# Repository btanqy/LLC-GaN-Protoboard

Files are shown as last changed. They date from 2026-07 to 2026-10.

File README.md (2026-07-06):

# LLC-GaN-Protoboard

This board will be a prototype GaN based LLC converter, with a target rating of 80W with 24V input to 400V output, ideally for renewable power conversion and high voltage applications in plasma generation. 

This board will be controlled by and mounted on top of the [LAUNCHXL-F28P55X](https://www.digikey.com/en/products/detail/texas-instruments/LAUNCHXL-F28P55X/22674628). It will be based on the reference design for TIDA-010062, minus the PFC element.

The board is made in KiCad while the code is done in Code Composer Studio by TI. 

Some resources that were used for reference during board design:
- [Pinout Map](https://www.ti.com/lit/ml/spaz056/spaz056.pdf?ts=1783172662507)
- [LaunchPad Hardware Design Guidelines](https://www.ti.com/lit/an/slaa542/slaa542.pdf)
- [F28P55X Datasheet](https://www.ti.com/lit/ds/sprsp85d/sprsp85d.pdf?ts=1783173915619)
- [Open Magnetics](https://openmagnetics.com)

- [LLC Topology](https://e2e.ti.com/cfs-file/__key/communityserver-discussions-components-files/196/Ch4.pdf)
- [LLC Switches and Tank](https://www.monolithicpower.com/learning/resources/understanding-llc-operation-part-i-power-switches-and-resonant-tank)
- [Example LLC Design](https://www.infineon.com/assets/row/public/documents/24/42/infineon-design-example-resonant-llc-converter-operation-and-design-applicationnotes-en.pdf)

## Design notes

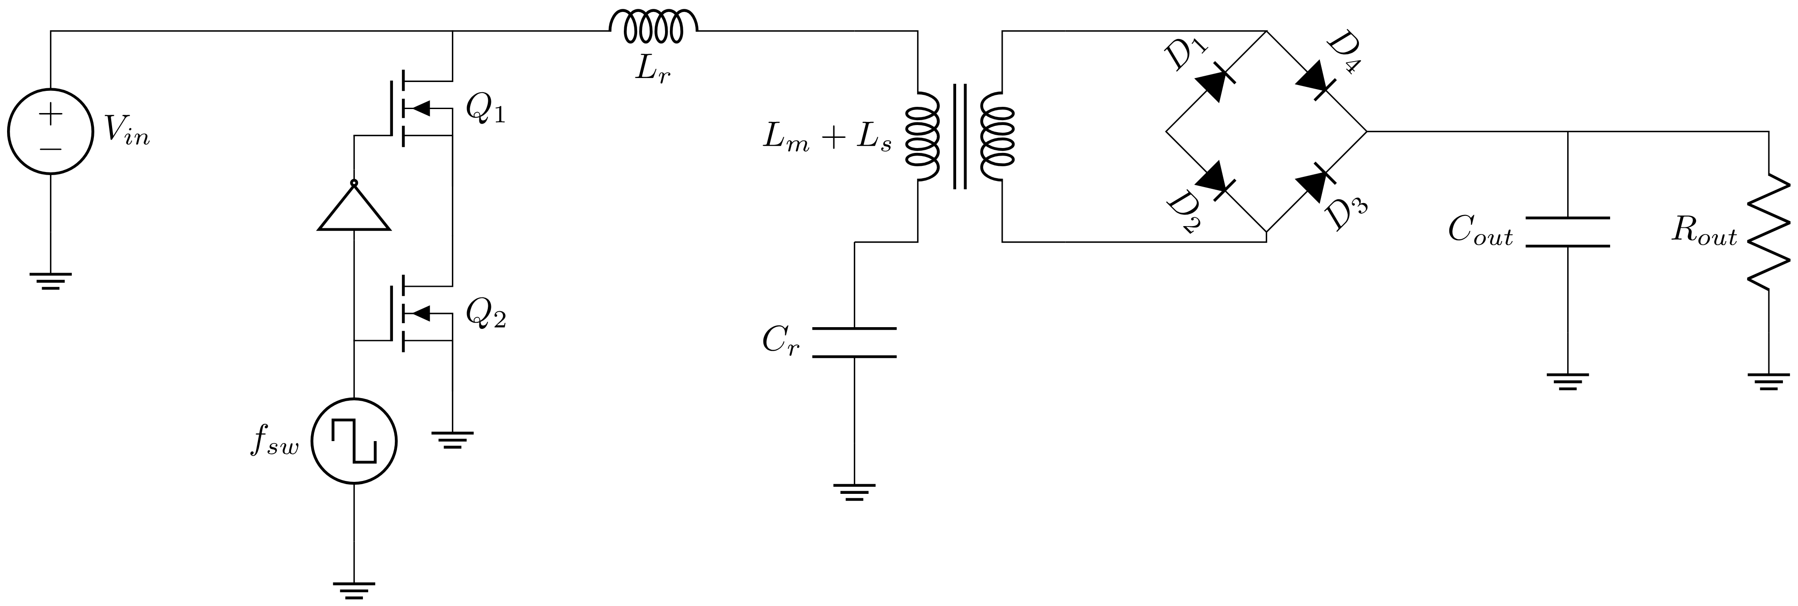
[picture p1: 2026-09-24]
circuitikz schematics/llc.png

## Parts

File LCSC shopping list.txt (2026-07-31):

2* 67996-420HLF (2x20 pin header)
2* FAN73912AMX (1200V half-bridge gate driver)
2* GAN7R0-150LBE (GAN)
2* 9561250802 (Ferrite core)
1* KAPTON-TAPE40MM (40mm polyimide insulation tape)
1* RT2010FKE075RL (75mΩ current sense resistor)
25* 5019 (PCB test points)
4* ADS12B3-ASARH (SiC schottky)
1* C1812C104KDRACTU (100nF ceramic capacitor, 1812 for rectifier)
1* C1206C302JCGACTU (3nF ceramic capacitor, 1206 for tank)
1* WSC25155R000FEA (5Ω current sense)
1* RT2010FKE075RL (50mΩ current sense)
10* C0603C104K5RACTU (0.1uF 0603 ceramic capacitor)
10* CL21B104KBCNNNC (1uf 0603 ceramic capacitor)
1* BU-P6883 (binding post)

2/20 turn transformer
ferrite core needs a 60um gap (1.08uh magnetizing inductance)
10 turns, 6.25 starting radius, 0.254 width, 0.4 spacing

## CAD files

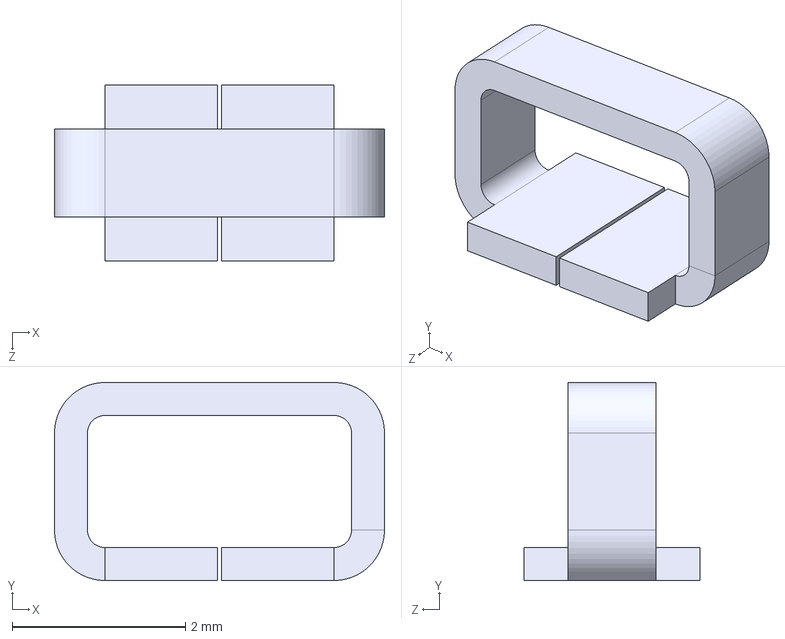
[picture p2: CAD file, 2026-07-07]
Parts/5019/3D/5019.stp
3.81 x 2.29 x 2.03 mm

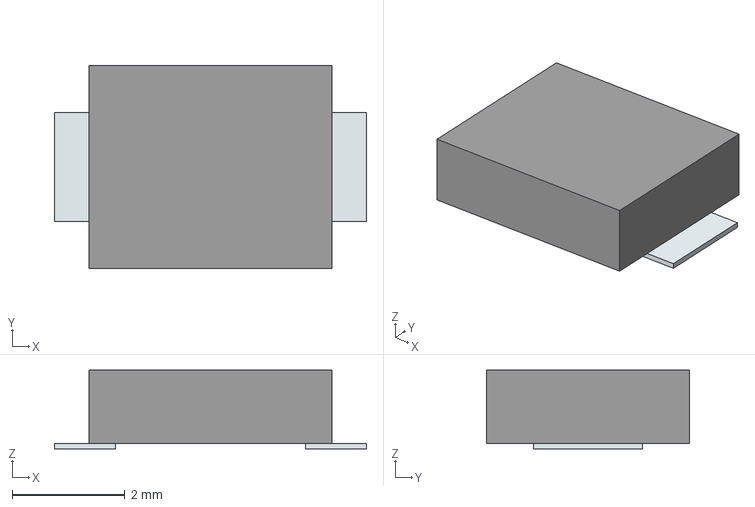
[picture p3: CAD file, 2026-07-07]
Parts/ADS12B3-ASARH/3D/ADS12B3-ASARH.stp
5.53 x 3.60 x 1.40 mm
Pins

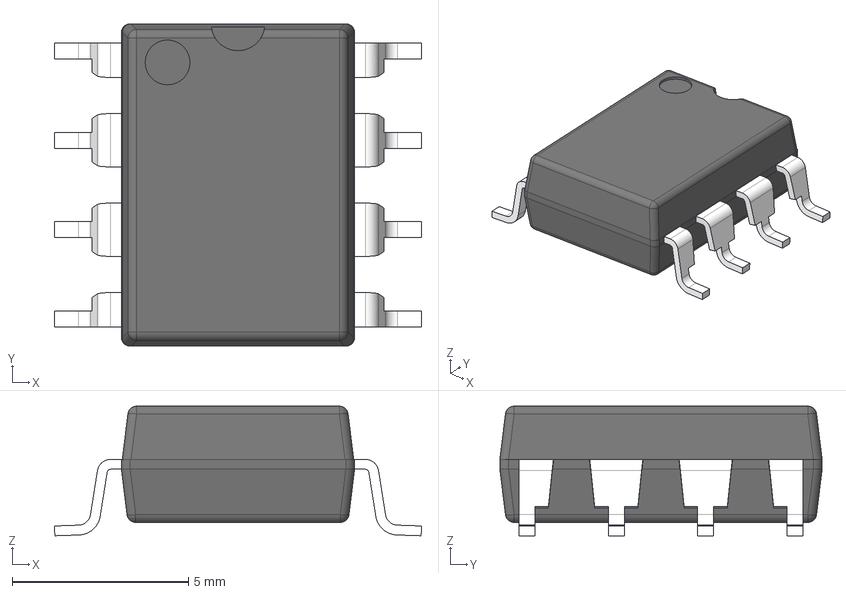
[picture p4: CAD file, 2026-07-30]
Parts/AMC1200SDUBR/AMC1200SDUBR/3D/AMC1200SDUBR.stp
10.4 x 9.15 x 3.68 mm
BODY-SO_AF0
LEAD-SO_AF1
LEAD-SO x 4
LEAD-SO_AF0
LEAD-SO_AF3
LEAD-SO_AF2

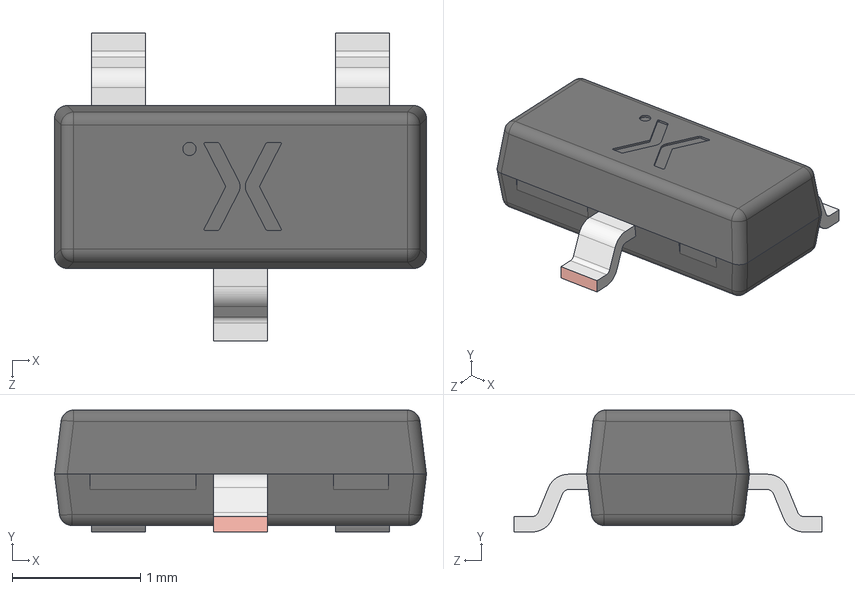
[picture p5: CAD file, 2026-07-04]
Parts/BZX84-C5V6,215/3D/BZX84-C5V6,215.stp
2.90 x 0.95 x 2.40 mm
SOT23 lower body
SOT23 Lead x 3
SOT23 Upper body

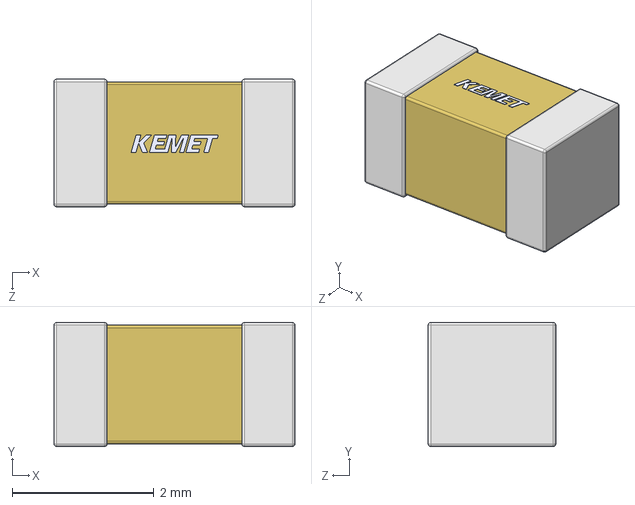
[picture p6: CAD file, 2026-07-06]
Parts/C1206C302JCGACTU/3D/C1206C302JCGACTU.stp
3.40 x 1.75 x 1.80 mm

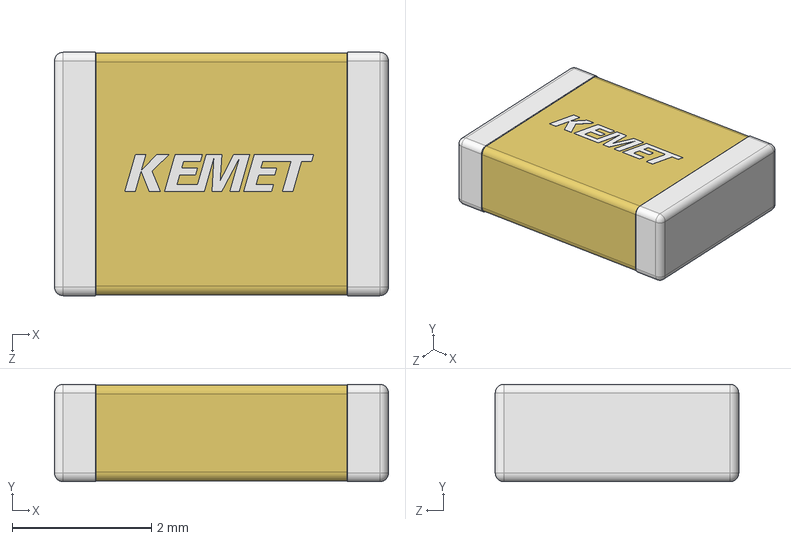
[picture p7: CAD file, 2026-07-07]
Parts/C1812C104KDRACTU/3D/C1812C104KDRACTU.stp
4.80 x 1.40 x 3.50 mm
Base_139
Termination_139 x 2

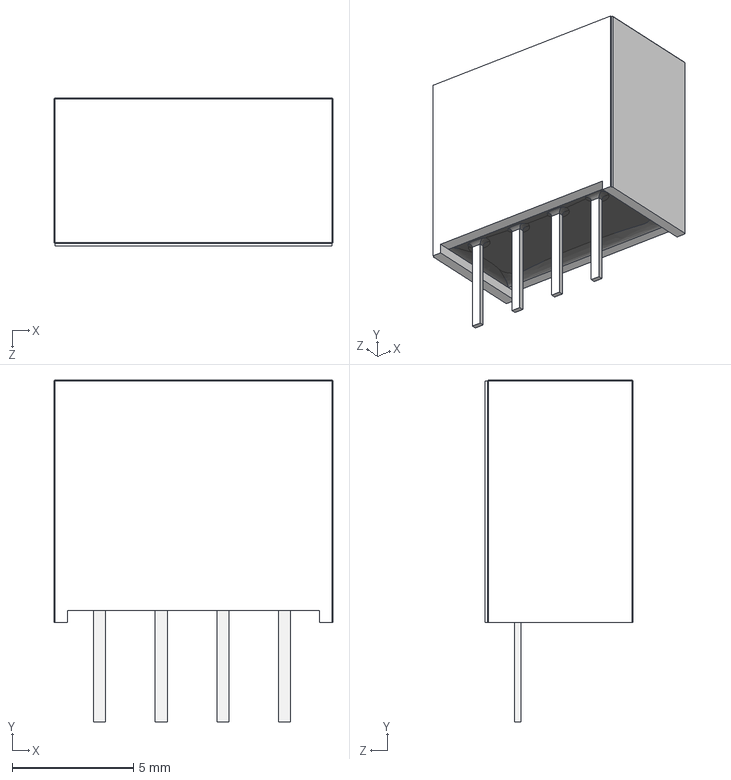
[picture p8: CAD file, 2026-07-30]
Parts/CME0303S3C/CME0303S3C/3D/CME0303S3C.stp
11.5 x 14.1 x 6.10 mm

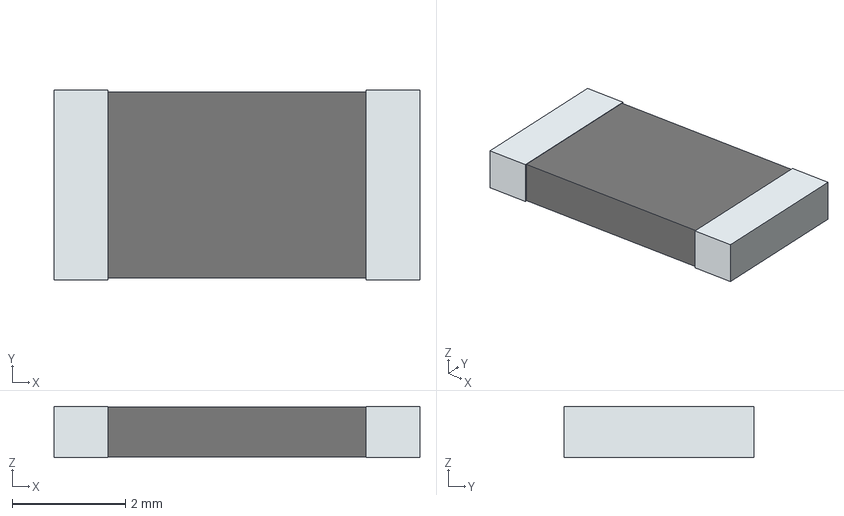
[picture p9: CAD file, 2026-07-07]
Parts/CRA2512-FZ-R050ELF/3D/CRA2512-FZ-R050ELF.stp
6.45 x 3.35 x 0.9 mm
term1
term2

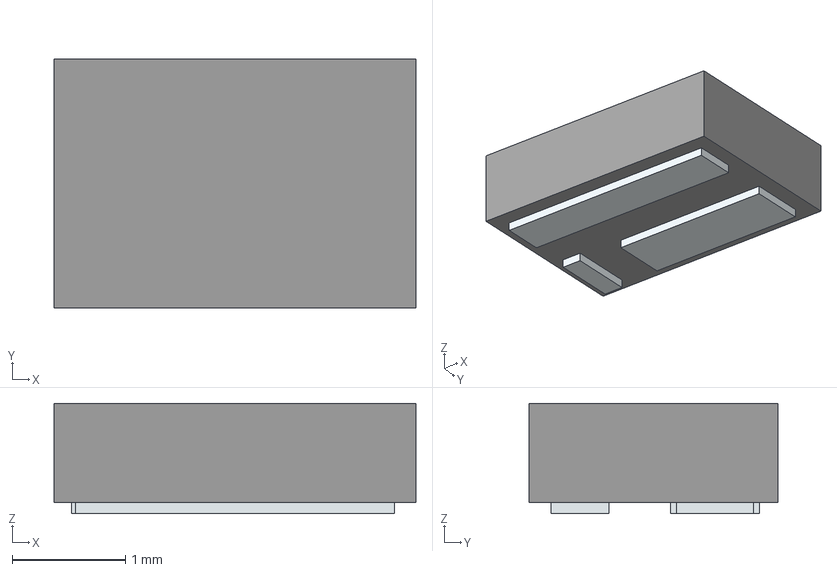
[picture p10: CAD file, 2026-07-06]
Parts/GAN7R0-150LBE/3D/GAN7R0-150LBE.stp
3.20 x 2.20 x 0.974 mm
Pins

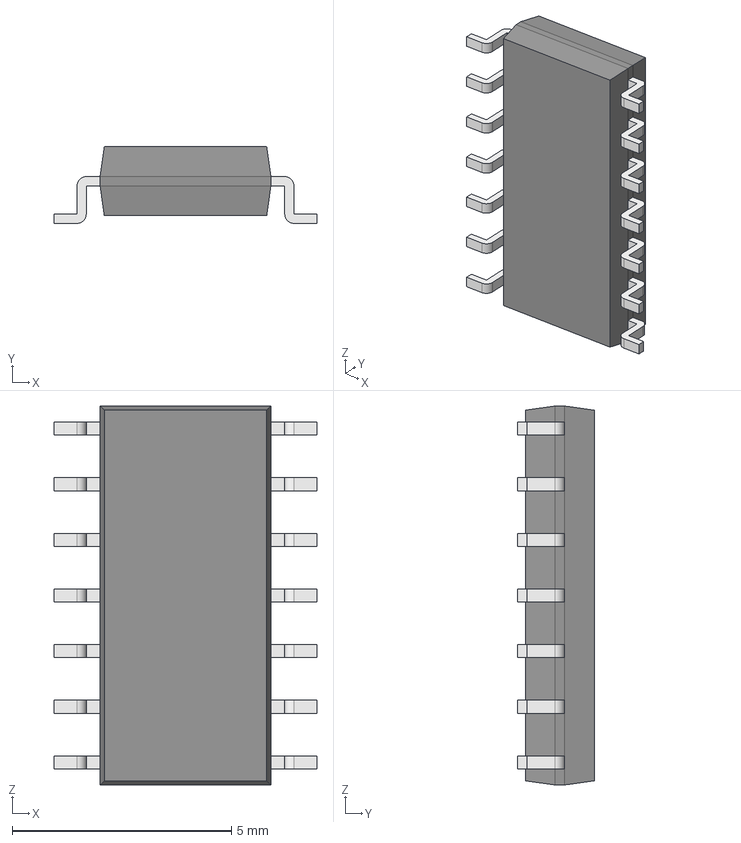
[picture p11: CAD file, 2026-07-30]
Parts/LM124DR/LM124DR.step
6.00 x 1.75 x 8.65 mm
Body001 (Mirror #1) x 7
XY-plane x 12
X-axis x 12

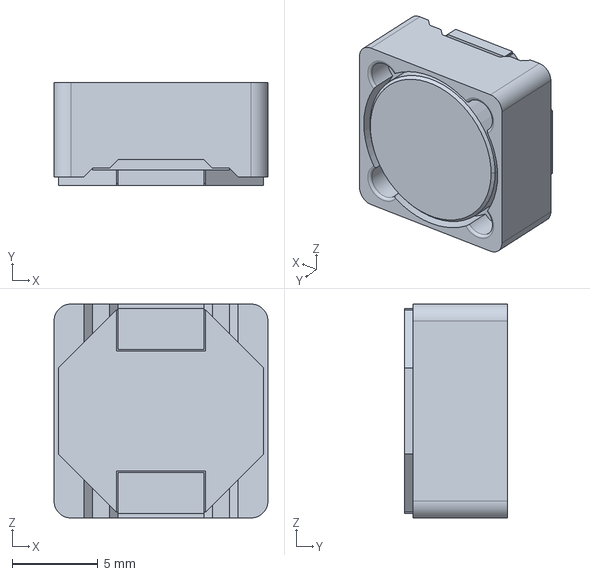
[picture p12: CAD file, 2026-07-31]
Parts/SRR1260-150M/SRR1260-150M/3D/SRR1260-150M.stp
12.5 x 6.00 x 12.5 mm

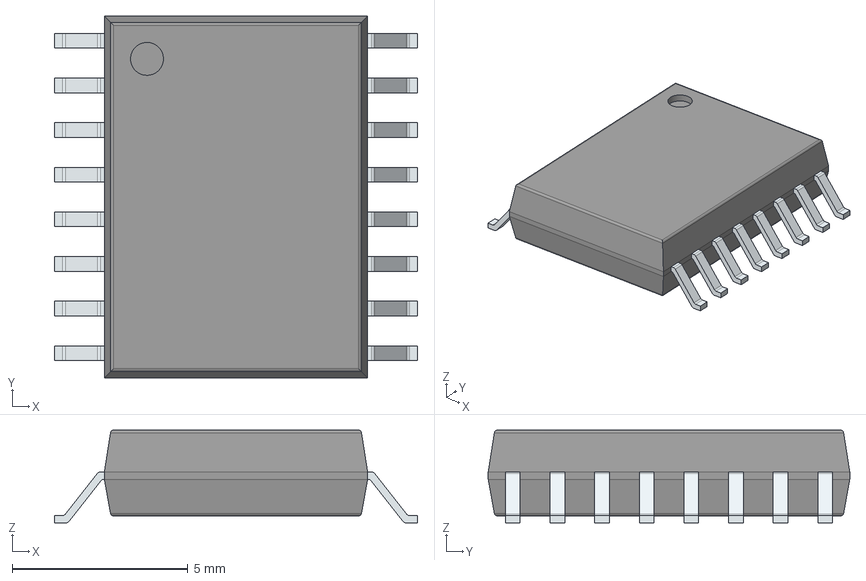
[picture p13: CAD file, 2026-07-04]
Parts/FAN73912AMX/3D/FAN73912AMX.stp
10.3 x 10.3 x 2.64 mm
PinsArrayLR

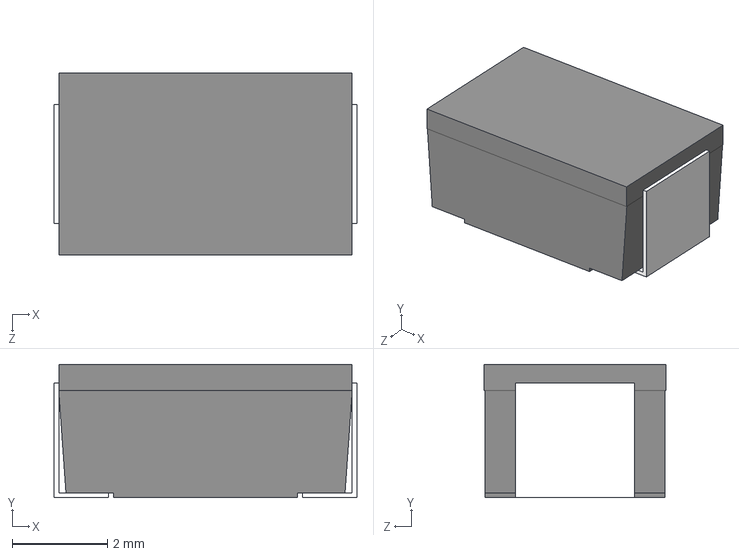
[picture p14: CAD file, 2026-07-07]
Parts/WSC25155R000FEA/3D/WSC25155R000FEA.stp
6.35 x 2.79 x 3.81 mm

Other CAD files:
Parts/5019/Allegro/5019.psm
Parts/5019/DEHDL/5019/chips/chips.prt
Parts/ADS12B3-ASARH/Allegro/ads12b3asarh.psm
Parts/ADS12B3-ASARH/DEHDL/ads12b3_asarh/chips/chips.prt
Parts/AMC1200SDUBR/AMC1200SDUBR/Allegro/sop254p1040x485-8n.psm
Parts/AMC1200SDUBR/AMC1200SDUBR/DEHDL/amc1200sdubr/chips/chips.prt
Parts/BZX84-C5V6,215/Allegro/sot95p230x110-3n.psm
Parts/BZX84-C5V6,215/DEHDL/bzx84_c5v6_215/chips/chips.prt
Parts/C1206C302JCGACTU/DEHDL/c1206c302jcgactu/chips/chips.prt
Parts/C1812C104KDRACTU/Allegro/c1812.psm
Parts/C1812C104KDRACTU/DEHDL/c1812c104kdractu/chips/chips.prt
Parts/CME0303S3C/CME0303S3C/Allegro/cme0303s3c.psm
Parts/CME0303S3C/CME0303S3C/DEHDL/cme0303s3c/chips/chips.prt
Parts/CRA2512-FZ-R050ELF/Allegro/resc6434x90n.psm
Parts/CRA2512-FZ-R050ELF/DEHDL/cra2512_fz_r050elf/chips/chips.prt
Parts/FAN73912AMX/Allegro/soic127p1032x264-16n.psm
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

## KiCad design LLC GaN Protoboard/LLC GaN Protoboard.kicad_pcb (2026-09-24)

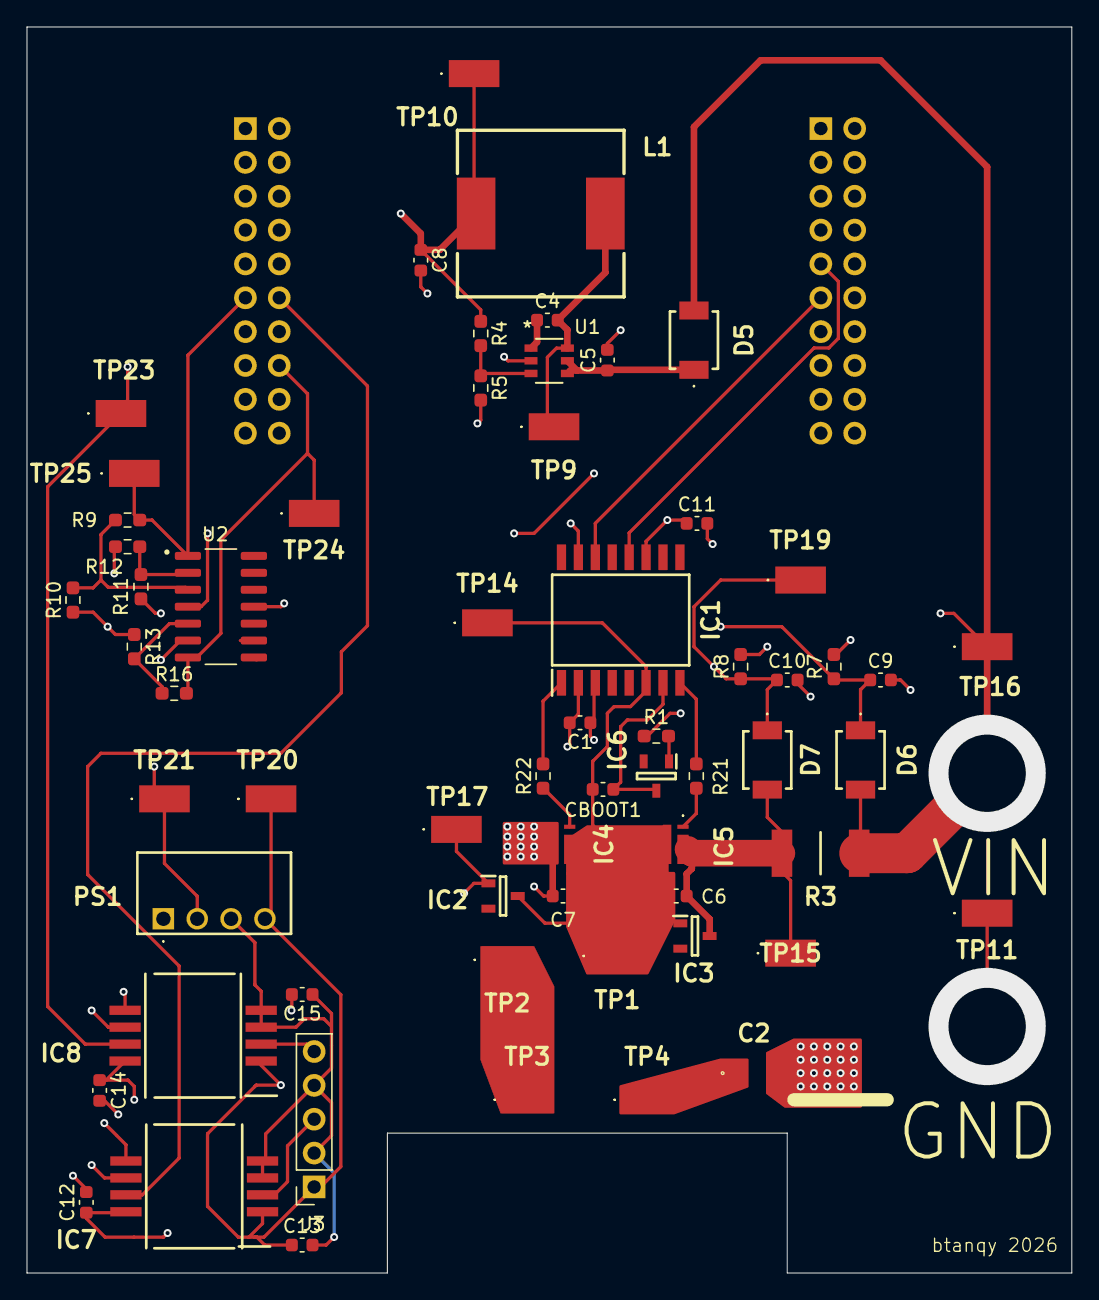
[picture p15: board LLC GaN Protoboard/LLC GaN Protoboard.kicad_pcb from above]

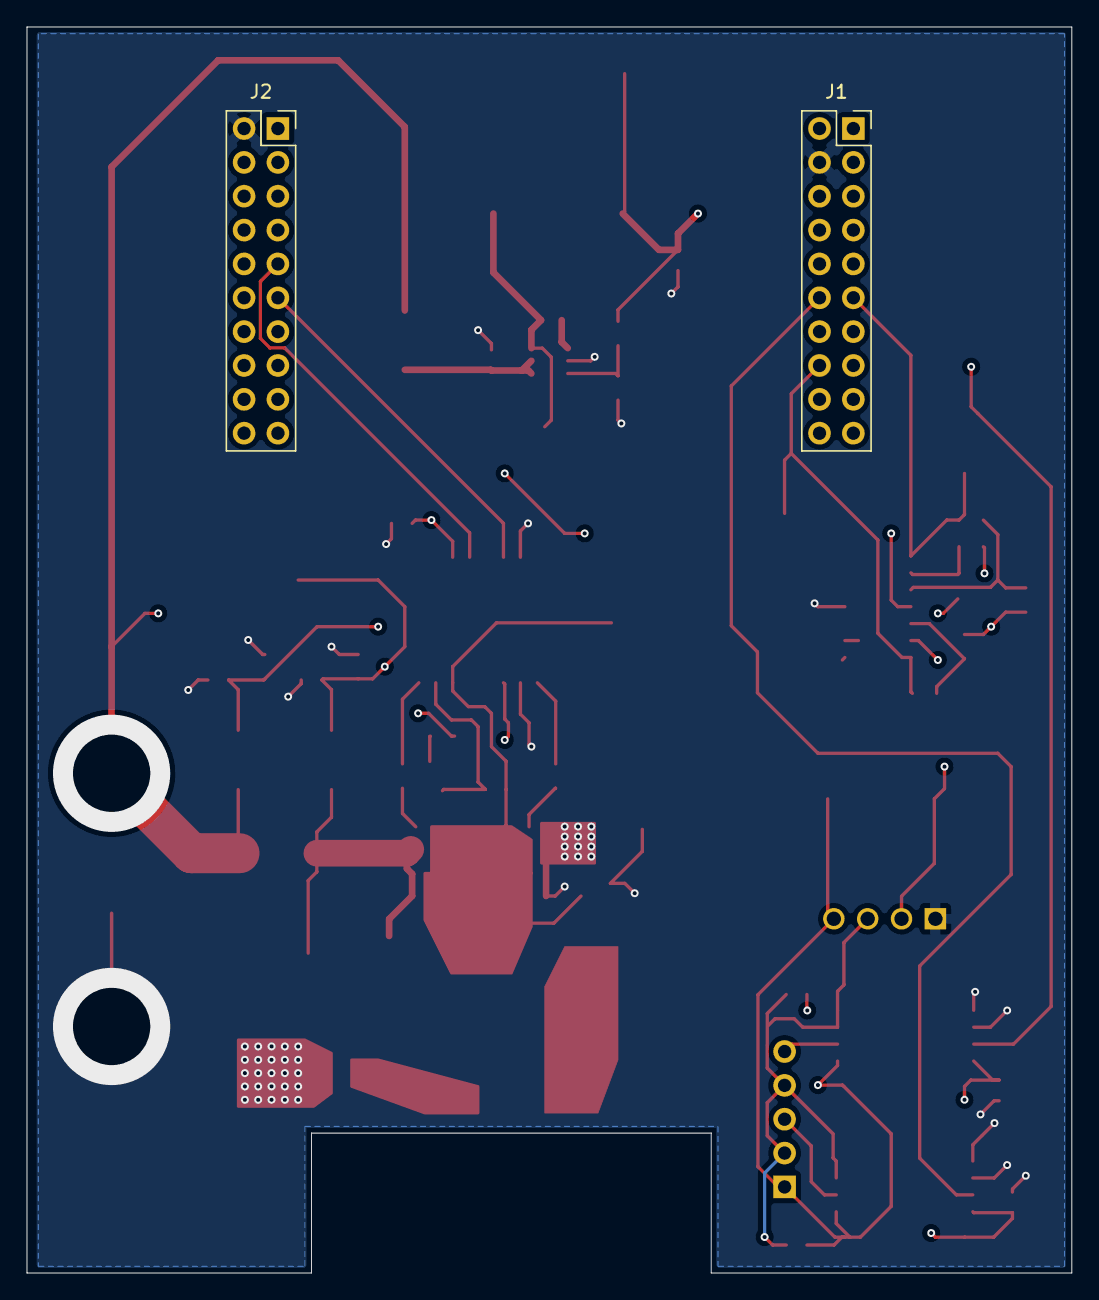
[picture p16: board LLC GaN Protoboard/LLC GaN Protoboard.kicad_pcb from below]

Board: 4 copper layers, 78.4 x 93.5 mm, 64 parts (2 on the bottom side), 31 nets.

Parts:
C1, C6, C7: 1u; C_0603_1608Metric
C2: C1206C302JCGACTU; C1206
C4: .1u; C_0603_1608Metric
C5: 2.2u; C_0603_1608Metric
C8: 22u; C_0603_1608Metric
C9, C10: 1n; C_0603_1608Metric
C11, C12, C13, C14, C15: 0.1u; C_0603_1608Metric
CBOOT1: C; C_0603_1608Metric
D5, D6, D7: ADS12B3-ASARH; ADS12B3ASARH
IC1: FAN73912AMX; SOIC127P1032X264-16N
IC2, IC3, IC6: BZX84-C5V6,215; SOT95P230X110-3N
IC4, IC5: GAN7R0-150LBE; GAN7R0150LBE
IC7, IC8: AMC1200SDUBR; SOP254P1040X485-8N
J1, J2: Conn_02x10_Odd_Even; PinSocket_2x10_P2.54mm_Vertical
J3: Conn_01x05_Pin; PinSocket_1x05_P2.54mm_Vertical
L1: SRR1260-150M
PS1: CME0303S3C
R1: 5; R_0603_1608Metric_Pad0.98x0.95mm_HandSolder
R3: CRA2512-FZ-R050ELF; RESC6434X90N
R4: 118k; R_0603_1608Metric_Pad0.98x0.95mm_HandSolder
R5: 22.1k; R_0603_1608Metric_Pad0.98x0.95mm_HandSolder
R7, R8: 1k; R_0603_1608Metric_Pad0.98x0.95mm_HandSolder
R9, R10, R11, R12, R13, R16: 10k; R_0603_1608Metric_Pad0.98x0.95mm_HandSolder
R21, R22: 1; R_0603_1608Metric_Pad0.98x0.95mm_HandSolder
TP1, TP2, TP3, TP4, TP9, TP10, TP11, TP14, TP15, TP16, TP17, TP19, TP20, TP21, TP23, TP24, TP25: 5019
U1: PLMR54410DBVR; U_SOT-23_TEX
U2: LM124DR; SOIC127P600X175-14N

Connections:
+3.3V: C11.1, C12.1, C14.1, IC1.11 (VDD), IC7.8 (VDD2), IC8.8 (VDD2), J1.1, PS1.2 (+VIN), R12.2, TP21.1 (1_1), U2.6 (2IN-)
+3.3V_ISO: C13.1, C15.2, IC7.1 (VDD1), IC8.1 (VDD1), J3.1, PS1.4 (+VOUT), TP20.1 (1_1)
+5V: C1.1, C8.1, IC1.3 (VCC), J1.2, L1.1, R1.1, R4.1, TP10.1 (1_1)
/LLC/FB: R4.2, R5.1, U1.3 (FB)
/LLC/GHIGH: IC1.8 (HO), R21.2
/LLC/GLOW: IC1.1 (LO), R22.2
/LLC/IIN_LOW: C6.2, D7.2 (A), IC3.3 (K), IC5.3 (D), R3.1, TP15.1 (1_1)
/LLC/IOUT_HIGH: IC7.2 (VINP), J3.3
/LLC/VB: CBOOT1.1, IC1.7 (VB), IC6.3 (K)
/LLC/VIN: D5.2 (A), D6.2 (A), R3.2, TP16.1 (1_1), U2.4 (VCC)
/LLC/VIN_RECT: C5.1, D5.1 (K), U1.4 (EN), U1.5 (VIN)
/LLC/VS: C6.1, C7.2, CBOOT1.2, IC1.6 (VS), IC2.3 (K), IC3.1 (A), IC4.3 (D), IC5.2 (S), TP1.1 (1_1), TP14.1 (1_1)
/Mount/ADCINB4/VOUT: IC8.7 (VOUTP), J1.14, TP23.1 (1_1)
/Sense/1IN+: R9.1, R10.2, U2.3 (1IN+)
/Sense/1IN-: R11.2, R12.1, U2.2 (1IN-)
/Sense/1OUT: J1.11, R9.2, TP25.1 (1_1), U2.1 (1OUT)
/Sense/2IN+: R13.2, R16.1, U2.5 (2IN+)
/Sense/2OUT: J1.16, R16.2, TP24.1 (1_1), U2.7 (2OUT)
/Sense/INV_HIGH: C9.1, D6.1 (K), R7.1, R10.1, R13.1
/Sense/INV_LOW: C10.1, D7.1 (K), R8.1, R11.1, TP19.1 (1_1)
/Sense/IOUT_VOUTP: IC7.7 (VOUTP), J1.12
/Sense/VINP: IC8.2 (VINP), J3.5
GND: C1.2, C2.2, C5.2, C7.1, C8.2, C9.2, C10.2, C11.2, C12.2, C14.2, IC1.2 (COM), IC1.15 (VSS), IC2.1 (A), IC4.2 (S), IC7.5 (GND2), IC7.6 (VOUTN), IC8.5 (GND2), IC8.6 (VOUTN), J1.4, J2.2, PS1.1 (-VIN), R5.2, R7.2, R8.2, TP11.1 (1_1), TP17.1 (1_1), U1.2 (GND), U2.11 (GND)
GND_ISO: C13.2, C15.1, IC7.3 (VINN), IC7.4 (GND1), IC8.3 (VINN), IC8.4 (GND1), J3.2, J3.4, PS1.3 (-VOUT)
unnamed: C2.1, TP4.1 (1_1)
unnamed: IC4.1 (G), R22.1
unnamed: IC5.1 (G), R21.1
unnamed: IC6.1 (A), R1.2
unnamed: TP2.1 (1_1), TP3.1 (1_1)
unnamed: C4.1, U1.1 (CB)
unnamed: C4.2, L1.2, TP9.1 (1_1), U1.6 (SW)

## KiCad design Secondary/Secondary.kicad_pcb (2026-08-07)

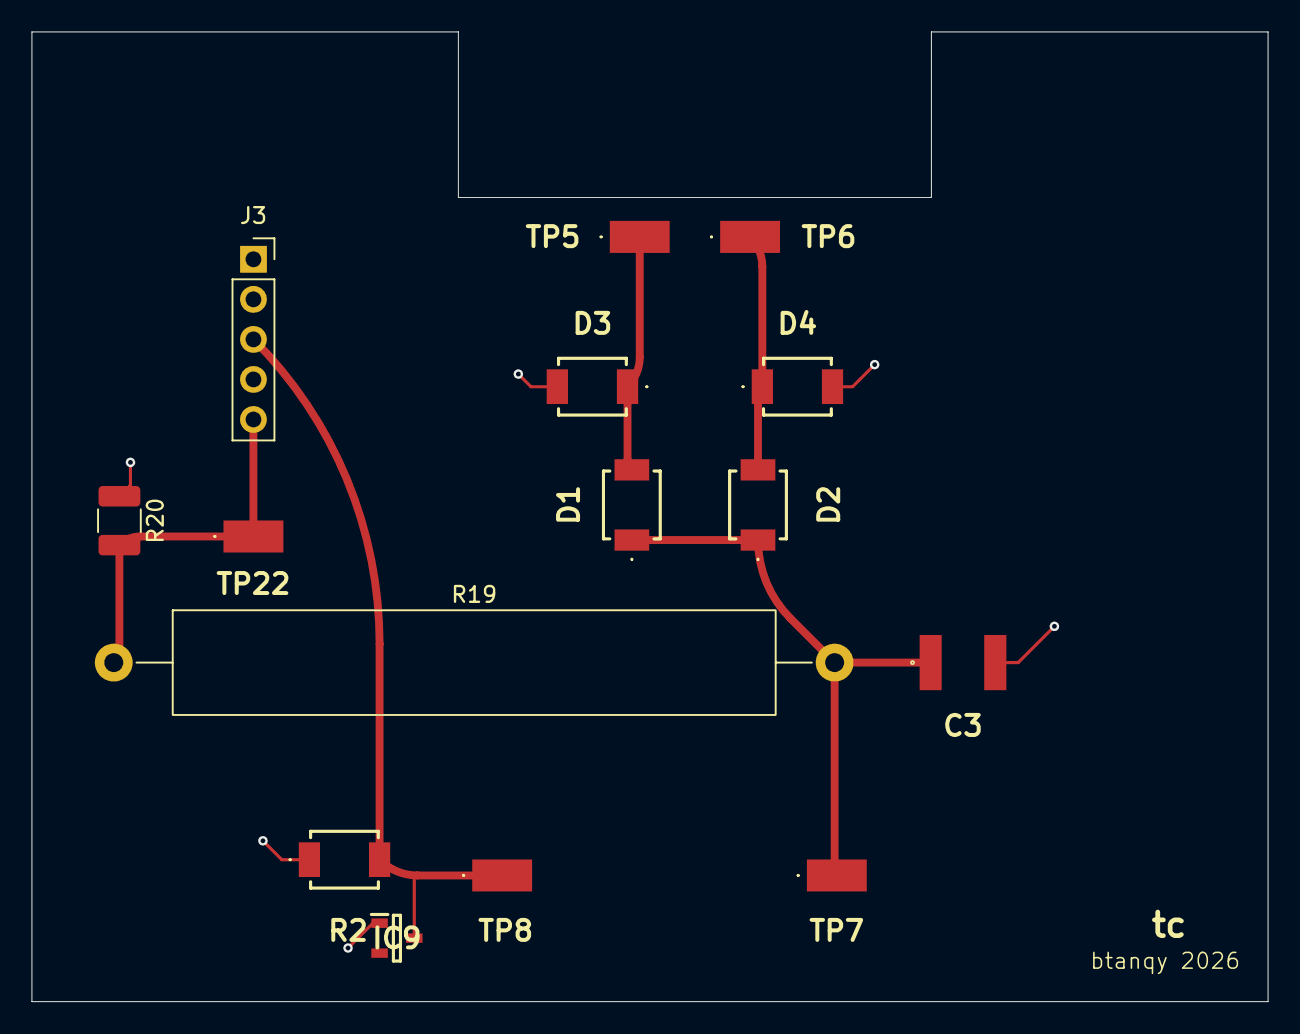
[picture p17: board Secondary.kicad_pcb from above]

Board: 4 copper layers, 78.4 x 61.5 mm, 15 parts (0 on the bottom side), 6 nets.

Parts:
C3: C1812C104KDRACTU; C1812
D1, D2, D3, D4: ADS12B3-ASARH; ADS12B3ASARH
IC9: BZX84-C5V6,215; SOT95P230X110-3N
J3: Conn_01x05_Pin; PinSocket_1x05_P2.54mm_Vertical
R2: WSC25155R000FEA; ADS12B3ASARH
R19: 90k; R_Axial_Power_L38.0mm_W6.4mm_P45.72mm
R20: 1k; R_1210_3225Metric_Pad1.30x2.65mm_HandSolder
TP5, TP6, TP7, TP8, TP22: 5019

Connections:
/IOUT_HIGH: IC9.3 (K), J3.3, R2.2, TP8.1 (1_1)
/VOUT: C3.1, D1.1 (K), D2.1 (K), R19.2, TP7.1 (1_1)
GND_ISO: C3.2, D3.2 (A), D4.2 (A), IC9.1 (A), J3.2, J3.4, R2.1, R20.1
unnamed: D1.2 (A), D3.1 (K), TP5.1 (1_1)
unnamed: D2.2 (A), D4.1 (K), TP6.1 (1_1)
unnamed: J3.5, R19.1, R20.2, TP22.1 (1_1)

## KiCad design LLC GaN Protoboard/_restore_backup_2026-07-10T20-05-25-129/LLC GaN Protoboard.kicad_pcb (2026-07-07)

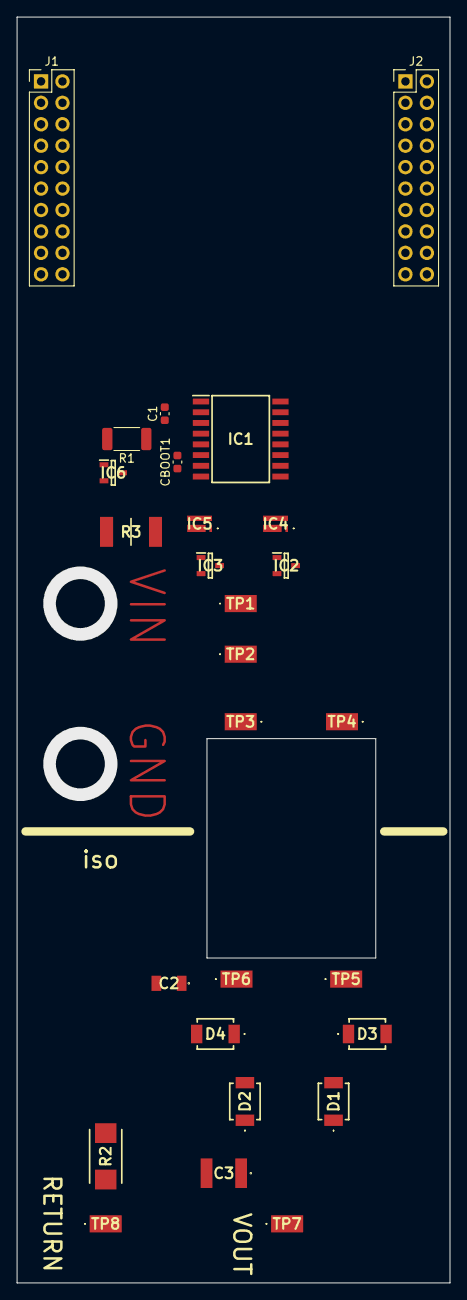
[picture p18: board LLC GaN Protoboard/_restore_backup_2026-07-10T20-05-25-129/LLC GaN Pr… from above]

Board: 2 copper layers, 51.3 x 150.0 mm, 27 parts (0 on the bottom side), 16 nets, no tracks yet.

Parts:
C1: 1u; C_0603_1608Metric
C2: C1206C302JCGACTU; C1206
C3: C1812C104KDRACTU; C1812
CBOOT1: C; C_0603_1608Metric
D1, D2, D3, D4: ADS12B3-ASARH; ADS12B3ASARH
IC1: FAN73912AMX; SOIC127P1032X264-16N
IC2, IC3, IC6: BZX84-C5V6,215; SOT95P230X110-3N
IC4, IC5: GAN7R0-150LBE; GAN7R0150LBE
J1, J2: Conn_02x10_Top_Bottom; PinHeader_2x10_P2.54mm_Vertical
R1: 5; R_2010_5025Metric
R2: WSC25155R000FEA; RESM6438X317N
R3: CRA2512-FZ-R050ELF; RESC6434X90N
TP1, TP2, TP3, TP4, TP5, TP6, TP7, TP8: 5019

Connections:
+5V: C1.1, IC1.3 (VCC), R1.1
/LLC/GHIGH: IC1.8 (HO), IC5.1 (G)
/LLC/GLOW: IC1.1 (LO), IC4.1 (G)
/LLC/IIN_LOW: IC3.3 (K), IC5.3 (D), R3.1, TP1.1 (1_1)
/LLC/IOUT_HIGH: R2.2, TP8.1 (1_1)
/LLC/VB: CBOOT1.1, IC1.7 (VB), IC6.3 (K)
/LLC/VOUT: C3.1, D1.1 (K), D2.1 (K), TP7.1 (1_1)
/LLC/VS: CBOOT1.2, IC1.6 (VS), IC2.3 (K), IC3.1 (A), IC4.3 (D), IC5.2 (S)
GND: C1.2, IC1.2 (COM), IC1.15 (VSS), J1.12, J2.11
GND_ISO: C3.2, D3.2 (A), D4.2 (A), R2.1
unnamed: C2.1, TP4.1 (1_1)
unnamed: D1.2 (A), D3.1 (K), TP5.1 (1_1)
unnamed: D2.2 (A), D4.1 (K), TP6.1 (1_1)
unnamed: IC6.1 (A), R1.2
unnamed: TP2.1 (1_1), TP3.1 (1_1)
PGND: C2.2, IC2.1 (A), IC4.2 (S)

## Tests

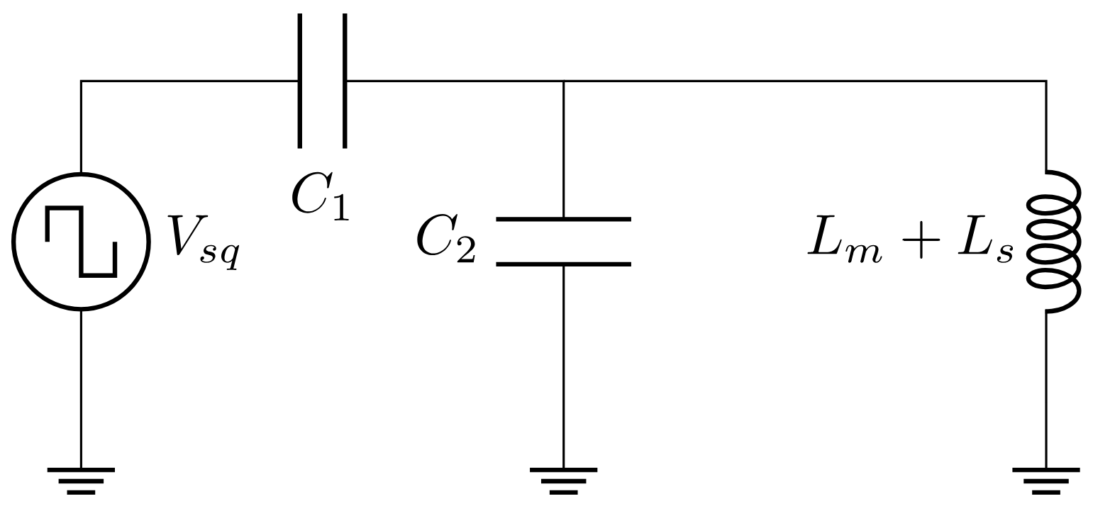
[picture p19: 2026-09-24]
circuitikz schematics/resonance_measurement.png

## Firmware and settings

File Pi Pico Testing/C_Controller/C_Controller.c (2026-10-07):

#include <stdio.h>
#include "pico/stdlib.h"
#include "hardware/gpio.h"
#include "hardware/adc.h"
#include "hardware/clocks.h"
#include "hardware/pio.h"
#include "PWM.pio.h"
#include "hardware/pll.h"
#include "hardware/vreg.h"

#pragma region INIT VALUES

// PLL
static uint32_t pll_freq;

// ADC
#define VOUTSENSE 26
static int vout_offset;
static int adc_meas;

// PIO for PWM
static PIO PWM = pio0;
#define SM 0
#define LO 0
#define HI 1
#define PINDIRS 3 // binary 0b11
static uint32_t pinmask = 0b11;
static uint offset;
#define BASE 0

#pragma endregion

// Output and tuning
static uint freq = 500000; // for initial frequency
static float deadtime = 0.03f;
static uint64_t current_time;
#define VSET 200
#define KP 0.06
#define KI 40
static uint integral;
#define DIVIDE_ROUND(a, b) (((a) + ((b) / 2)) / (b))
#define CONTROLLER_FREQ    10000U
#define LOOP_DT            DIVIDE_ROUND(1000000U, CONTROLLER_FREQ) // timer counts once per us
#define ADCPERVOLT 4.55
#define FREQPERVOLT 5000u
#define HICLAMP 500000u
#define LOCLAMP 310000u

#pragma region DEFS

// PIO setup on pins 0 and 1
static inline void PWM_setup(PIO pio, uint sm, uint lo, uint hi, uint pindirs, uint32_t mask, uint offset, uint base){
    pio_gpio_init(pio, lo);
    pio_gpio_init(pio, hi);
    pio_sm_set_pindirs_with_mask(pio, sm, pindirs, mask);
    pio_sm_config c = PWM_program_get_default_config(offset);
    sm_config_set_sideset_pins(&c, base);
    sm_config_set_out_shift(&c, true, false, 16); // 16 is just pull_threshold
    sm_config_set_fifo_join(&c, PIO_FIFO_JOIN_TX);

    pio_sm_init(pio, sm, offset, &c);
    //pio_sm_set_enabled(pio, sm, true); // enables are called later
}

static inline void PWM_set_freq(PIO pio, uint sm, uint32_t active_counter, uint32_t deadtime_counter){
    if (!pio_sm_is_tx_fifo_full(pio, sm)){
        pio_sm_put(pio, sm, (uint32_t)deadtime_counter << 20 | active_counter);
    }
}

typedef struct{
    uint32_t active;
    uint32_t deadtime;
} PWM_cycles;

PWM_cycles PWM_target_freq(uint freq, uint32_t pll_freq, float deadtime){
    // request some frequency, given pll frequency, and percentage of deadtime (0.01 = 1% deadtime)
    // minimum of 12 cycles, and an additional 2 cycles for each active and deadtime
    uint approx_cycles = (uint) (pll_freq / (2 * freq));
    uint approx_deadtime = (uint) (approx_cycles * deadtime);
    int deadtime_cycles = approx_deadtime - 5; // amount of required dead cycles
    if (deadtime_cycles < 0){
        deadtime_cycles = 0;
    }
    int active_cycles = approx_cycles -  deadtime_cycles;
    if (active_cycles < 0){
        active_cycles = 0;
    }
    return (PWM_cycles){active_cycles, deadtime_cycles};
}

static double clamp(double value){
    if (value > HICLAMP){
        value = HICLAMP;
    }
    if (value < LOCLAMP){
        value = LOCLAMP;
    }
    return value;
}

// Pulsing

static inline void disable_sm(PIO pio, uint sm) {
    pio_sm_set_enabled(pio, sm, false);
    pio_sm_clear_fifos(pio, sm);
    pio_sm_restart(pio, sm);
    pio_sm_exec(pio, sm, pio_encode_jmp(offset));
    pio_sm_set_pins_with_mask(pio, sm, 0, pinmask);
}

static inline void enable_sm(PIO pio, uint sm, PWM_cycles counters){
    PWM_set_freq(pio, sm, counters.active, counters.deadtime); 
    pio_sm_set_enabled(pio, sm, true);
}

// Quick conversion methods

static double adc_to_vout(int adc_values){
    return adc_values / ADCPERVOLT;
}

static double vout_to_freq(double vout){
    return vout * FREQPERVOLT;
}

#pragma endregion

int main()
{
    #pragma region INITS

    vreg_set_voltage(VREG_VOLTAGE_1_15);
    sleep_ms(10);

    // PLL STUFF
    set_sys_clock_pll(1500 * MHZ, 6, 1);
    pll_freq = clock_get_hz(clk_sys);

    // stdio_init_all(); causes this to hang without usb??
    adc_init();

    sleep_ms(10000);

    // ADC STUFF
    adc_gpio_init(VOUTSENSE); // Pin 26
    adc_select_input(0); // 0-3 is 26-29 on board
    // not really sure whether its good to let the adc run or not, but configuring it to not run for now
    //adc_run(true);
    vout_offset = adc_read();
    // technically overclocking the adc up to 4MS/s is possible, but keeping it at base frequency means no glitches
    //clock_configure(clk_adc, CLK_DEST_SYS_CLOCKS, CLOCKS_CLK_ADC_CTRL_AUXSRC_VALUE_CLKSRC_PLL_SYS, pll_freq, pll_freq);

    //PWM STUFF
    offset = pio_add_program(PWM, &PWM_program);
    PWM_setup(PWM, SM, LO, HI, PINDIRS, pinmask, offset, BASE);

    #pragma endregion

    // Startup first
    PWM_cycles target_freq = PWM_target_freq(freq, pll_freq, deadtime);
    PWM_set_freq(PWM, SM, target_freq.active, target_freq.deadtime);
    enable_sm(PWM, SM, target_freq);
    sleep_us(200);
    uint elapsed;
    double vout;
    double error;
    integral = 0;

    while (true) {
        for (uint i = 0; i < 100; i++){
            current_time = time_us_64(); // ensure accurate loop time

            // Control here

            //averaged vout
            adc_meas = 0;
            for (uint ii = 0; ii < 5; ii++){
                adc_meas += adc_read();
            }
            vout = adc_to_vout((int)(adc_meas/5) - vout_offset);
            error = vout_to_freq(vout - VSET);
            integral += KI * error * LOOP_DT / 1e6;
            freq = (uint) clamp(freq + (double)(KP * error) + (double)integral); // scale loop dt to seconds from microseconds
            target_freq = PWM_target_freq(freq, pll_freq, deadtime);
            PWM_set_freq(PWM, SM, target_freq.active, target_freq.deadtime);

            elapsed = time_us_64() - current_time;
            while (elapsed < LOOP_DT){
                elapsed = time_us_64() - current_time;
            }
        }
        disable_sm(PWM, SM);
        sleep_ms(5000);
        freq = 500000;
        target_freq = PWM_target_freq(freq, pll_freq, deadtime);
        enable_sm(PWM, SM, target_freq);
        sleep_us(100);
    }
}

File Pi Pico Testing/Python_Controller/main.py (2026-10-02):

from machine import mem32
from time import sleep, sleep_us
from machine import ADC

IO_BANK0_BASE = 0x40014000
GPIO0_CTRL = IO_BANK0_BASE + 0x004
GPIO2_CTRL = IO_BANK0_BASE + 0x014

PLL_SYS_BASE = 0x40028000
CS = PLL_SYS_BASE + 0x0
PWR = PLL_SYS_BASE + 0x4
FBDIV_INT = PLL_SYS_BASE + 0x08
PRIM = PLL_SYS_BASE + 0xc

PWM_BASE = 0x40050000
CH0_CSR = PWM_BASE + 0x00
CH0_DIV = PWM_BASE + 0x04
CH0_CC  = PWM_BASE + 0x0c
CH0_TOP = PWM_BASE + 0x10
CH0_CTR = PWM_BASE + 0x08
CH1_CSR = PWM_BASE + 0x14
CH1_DIV = PWM_BASE + 0x18
CH1_CC  = PWM_BASE + 0x20
CH1_TOP = PWM_BASE + 0x24
CH1_CTR = PWM_BASE + 0x1c
EN      = PWM_BASE + 0xa0

# ---- PLL setup ----
mem32[CS] = 1 << 0
mem32[PWR] &= ~((1 << 0) | (1 << 5))
mem32[FBDIV_INT] = 100 << 0
mem32[PRIM] = (6 << 16) | (1 << 12)
while (mem32[CS] & (1 << 31)) == 0:
    pass

# ---- Frequency limits (TUNE THESE to your measured resonant freq) ----
# freq = 200MHz / (top+1)
TOP_START = 400   # ~570 kHz, well above resonance for a soft start
TOP_MIN   = 300   # ~664 kHz max switching freq (light-load limit)
TOP_MAX   = 600    # ~355 kHz -- keep margin ABOVE measured resonance (350kHz)
                   # do not let this reach/cross the actual resonant point

DEADTIME  = 15     # counts, at 200MHz -> 75ns, adjust if you want 50ns (11-12 counts)
PHASE_OFF = 10      # extra counts added to CH1 offset

def apply_top(top):
    half = top // 2
    mem32[CH0_CC]  = half - DEADTIME
    mem32[CH0_TOP] = top
    mem32[CH1_CC]  = half - DEADTIME
    mem32[CH1_TOP] = top
    return half

def start_pwm(top):
    half = apply_top(top)
    mem32[CH0_CTR] = 0
    mem32[CH1_CTR] = half + PHASE_OFF   # set phase ONCE per enable
    mem32[EN] = 0b11
    sleep_us(100)

# ---- PWM slice config ----
mem32[EN] = 0b00
mem32[CH0_CSR] = 0b00001001
mem32[CH0_DIV] = 1 << 4
mem32[CH1_CSR] = 0b00001001
mem32[CH1_DIV] = 1 << 4
apply_top(TOP_START)

sleep(10)

mem32[GPIO0_CTRL] = 4
mem32[GPIO2_CTRL] = 4

top_value = TOP_START
start_pwm(top_value)

# ---- PI controller ----
KP = 0.0013/20
KI = 14/20          # start conservative; tune experimentally, see note below
LOOP_DT = 200e-6    # approx loop period (sleep_us(10)+sleep_us(100)+overhead)

vout = ADC(26)
zero_offset = vout.read_u16()
vset = 200
vset_adc = int(zero_offset + 65535 * (0.00225 * vset) / 3.3)

integral = 0.0

def clamp(x, lo, hi):
    return lo if x < lo else hi if x > hi else x


while True:
    for i in range(300):
        vout_meas = 0
        for ii in range(10):
            vout_meas += vout.read_u16() / 10
            sleep_us(1)
        error = vset_adc - int(vout_meas)

        integral_try = integral + error * LOOP_DT
        candidate = clamp(TOP_START + KP * error + KI * integral_try, TOP_MIN, TOP_MAX)
        if TOP_MIN < candidate < TOP_MAX:   # strict inequality: don't integrate further once saturated
            integral = integral_try

        top_value = int(clamp(TOP_START + KP * error + KI * integral, TOP_MIN, TOP_MAX))
        apply_top(top_value)
        sleep_us(1)

    mem32[EN] = 0b00
    sleep(10)
    start_pwm(TOP_START)   # re-apply phase offset on every restart

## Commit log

2026-07-04 Added parts and schematics
    [BZX84-C5V6,215.stp, BZX84-C5V6_215.SchLib, EDI2CAP.CFG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]
2026-07-05 Added calculations
    [Calculations.ods]
2026-07-06 Added more calculations
    [C1206C302JCGACTU.stp, Calculations.ods, EDI2CAP.CFG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]
2026-07-07 Initial layout
    [5019.PcbLib, 5019.SchLib, 5019.psm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]
2026-07-07 outlined transformer
    [Transformer.kicad_pcb]
2026-07-29 Edited layout
    [LLC GaN Protoboard.kicad_pcb, LLC GaN Protoboard.kicad_sch, LLC.kicad_sch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]
2026-07-30 Finished schematic
    [AMC1200SDUBR.SchLib, AMC1200SDUBR.stp, CME0303S3C.PcbLib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]
2026-07-31 Edited schematic
    [LLC GaN Protoboard.kicad_sch, LLC.kicad_sch, Mount.kicad_sch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]
2026-07-31 first route
    [EDI2CAP.CFG, LLC GaN Protoboard.kicad_pcb, LLC GaN Protoboard.kicad_sch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]
2026-07-31 Updated transformer
    [Transformer.kicad_pcb]
2026-08-01 Finished transformer
    [Transformer.kicad_pcb]
2026-08-01 Added vias to transformer blanks
    [Transformer.kicad_pcb]
2026-08-01 Initial primary side layout
    [LLC GaN Protoboard.kicad_pcb, LLC GaN Protoboard.kicad_sch, LLC.kicad_sch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]
2026-08-01 Layout for secondary
    [LLC GaN Protoboard.kicad_pcb, Secondary.kicad_pcb, Secondary.kicad_sch]
2026-08-01 Fixed transformer boards
    [More Transformer.kicad_pcb, More Transformer.kicad_sch, Transformer.kicad_pcb]
2026-08-03 Added open spots for soldering
    [LLC GaN Protoboard.kicad_pcb, LLC.kicad_sch, Sense.kicad_sch]
2026-08-07 Added secondary clamp and swapped components
    [LLC GaN Protoboard.kicad_pcb, LLC.kicad_sch, Secondary.kicad_pcb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]
2026-09-07 created pwm pulse code
2026-09-24 edited derated calculations
    [Calculations.ods, Calculations_Derated.ods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]
2026-09-25 added graphs for 2:85 turn derated converter
    [Tank Gain - 20kOhm, 2-85 turns.ods]
2026-10-03 added pio pwm
2026-10-04 added c pwm code for testing
2026-10-04 fixed pwm
2026-10-04 verified and fixed c controller code under pulsing
    [C_Controller.c, C_PWM.c]
